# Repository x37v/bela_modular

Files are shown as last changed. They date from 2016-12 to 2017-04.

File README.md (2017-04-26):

# bela_modular

A modular level interface for the bela beagle bone black cape, kicad projects.

[bela](http://bela.io/) is a cape for the beagle bone black

* based off the [audio expansion cape](http://blog.bela.io/analogue-vs-digital/)
* [hardware info](https://github.com/BelaPlatform/Bela/wiki/Hardware-explained)

## Pin mappings

The digital i/o is mapped as such:

|Bela #|	 Board | Note 	 |
|---|--- | ---|
|00 |  in 1 ||
|01 |  in 2 ||
|02 |  in 3 ||
|03 |  in 4 ||
|04 |  digtial in enable | pull low to enable |
|05 |  vfd ctrl enable | pull low to enable |
|06 |  encin2-btn ||
|07 |  encin2-b ||
|08 |  out 1 ||
|09 |  out 2 ||
|10 |  encin2-a ||
|11 |  out 3 ||
|12 |  out 5 ||
|13 |  out 4 ||
|14 |  out 7 ||
|15 |  out 6 ||

### VFD IO

| P8 | | gpio | note |
|:--:|---|---|-- |
| 12 | ctrl enable | 1_12 | mapped in bela software |
| 14 | digital out enable | 0_26 | |
| 31 | P busy in | 0_10 | |
| 34 | vDE | 2_17 | |
| 35 | CS2 | 0_8  | |
| 36 | CS1 | 2_16 | |
| 37 | /RD and RW | 2_14 | |
| 38 | /WR and RS | 2_15 | |
| | | | |
| 39 | D7 | 2_12 | |
| 40 | D6 | 2_13 | |
| 41 | D5 | 2_10 | |
| 42 | D4 | 2_11 | |
| 43 | D3 | 2_8  | |
| 44 | D2 | 2_9  | |
| 45 | D1 | 2_6  | |
| 46 | D0 | 2_7  | |

### Errors/rework

The digital 'extra' board from 3/17 requires a rework for the digital out and
control enable pins [P8 12 and 14]. These should be detached from 5V and
attached to 3.3V.

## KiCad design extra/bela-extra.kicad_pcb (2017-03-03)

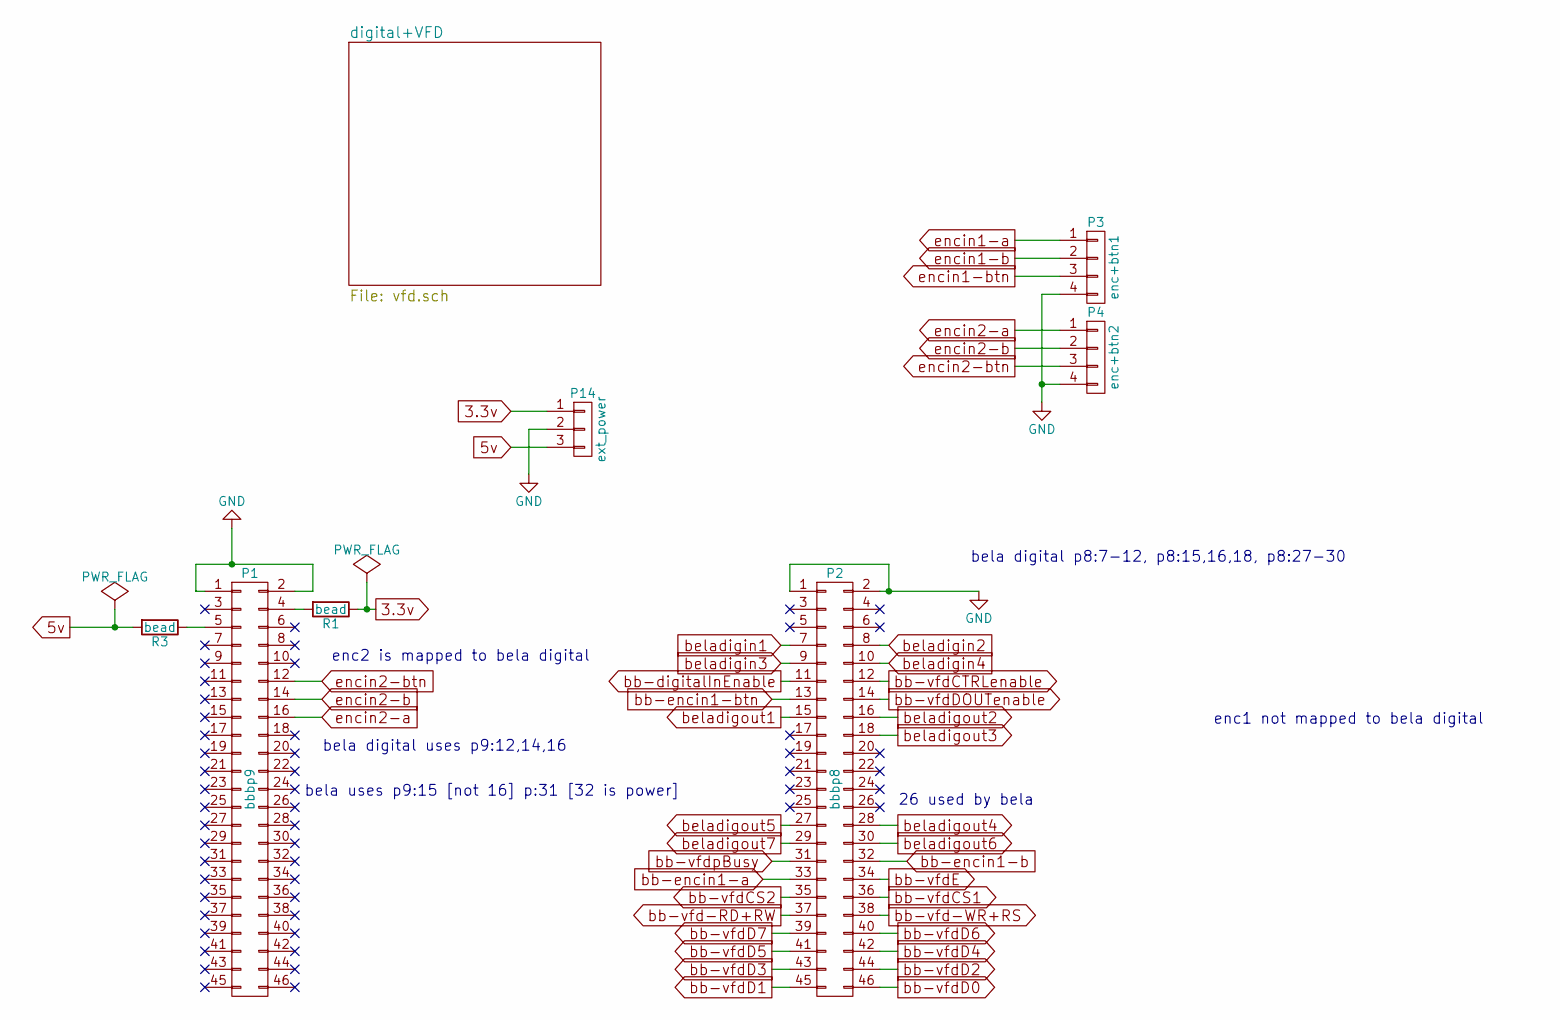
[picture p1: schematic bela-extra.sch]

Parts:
P1: bbbp9; Pin_Header_Straight_2x23_Pitch2.54mm
P2: bbbp8; Pin_Header_Straight_2x23_Pitch2.54mm
P3: enc+btn1; Pin_Header_Straight_1x04_Pitch2.54mm
P4: enc+btn2; Pin_Header_Straight_1x04_Pitch2.54mm
P14: ext_power; Pin_Header_Straight_1x03_Pitch2.54mm
R1, R3: bead; Resistor_Vertical_RM5mm-xnor

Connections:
3.3v: P14.1, R1.1; also elsewhere on the board
5v: P14.3, R3.2; also elsewhere on the board
GND: P1.1, P1.2, P2.1, P2.2, P3.4, P4.4, P14.2; also elsewhere on the board
unnamed: P1.4, R1.2
unnamed: P1.5, R3.1
bb-digitalInEnable: P2.11; also elsewhere on the board
bb-encin1-a: P2.33; also elsewhere on the board
bb-encin1-b: P2.32; also elsewhere on the board
bb-encin1-btn: P2.13; also elsewhere on the board
bb-vfd-RD+RW: P2.37; also elsewhere on the board
bb-vfd-WR+RS: P2.38; also elsewhere on the board
bb-vfdCS1: P2.36; also elsewhere on the board
bb-vfdCS2: P2.35; also elsewhere on the board
bb-vfdCTRLenable: P2.12; also elsewhere on the board
bb-vfdD0: P2.46; also elsewhere on the board
bb-vfdD1: P2.45; also elsewhere on the board
bb-vfdD2: P2.44; also elsewhere on the board
bb-vfdD3: P2.43; also elsewhere on the board
bb-vfdD4: P2.42; also elsewhere on the board
bb-vfdD5: P2.41; also elsewhere on the board
bb-vfdD6: P2.40; also elsewhere on the board
bb-vfdD7: P2.39; also elsewhere on the board
bb-vfdDOUTenable: P2.14; also elsewhere on the board
bb-vfdE: P2.34; also elsewhere on the board
bb-vfdpBusy: P2.31; also elsewhere on the board
beladigin1: P2.7; also elsewhere on the board
beladigin2: P2.8; also elsewhere on the board
beladigin3: P2.9; also elsewhere on the board
beladigin4: P2.10; also elsewhere on the board
beladigout1: P2.15; also elsewhere on the board
beladigout2: P2.16; also elsewhere on the board
beladigout3: P2.18; also elsewhere on the board
beladigout4: P2.28; also elsewhere on the board
beladigout5: P2.27; also elsewhere on the board
beladigout6: P2.30; also elsewhere on the board
beladigout7: P2.29; also elsewhere on the board
encin1-a: P3.1; also elsewhere on the board
encin1-b: P3.2; also elsewhere on the board
encin1-btn: P3.3; also elsewhere on the board
encin2-a: P1.16, P4.1
encin2-b: P1.14, P4.2
encin2-btn: P1.12, P4.3

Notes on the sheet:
enc1 not mapped to bela digital
enc2 is mapped to bela digital
26 used by bela
bela uses p9:15 [not 16] p:31 [32 is power]
bela digital p8:7-12, p8:15,16,18, p8:27-30
bela digital uses p9:12,14,16

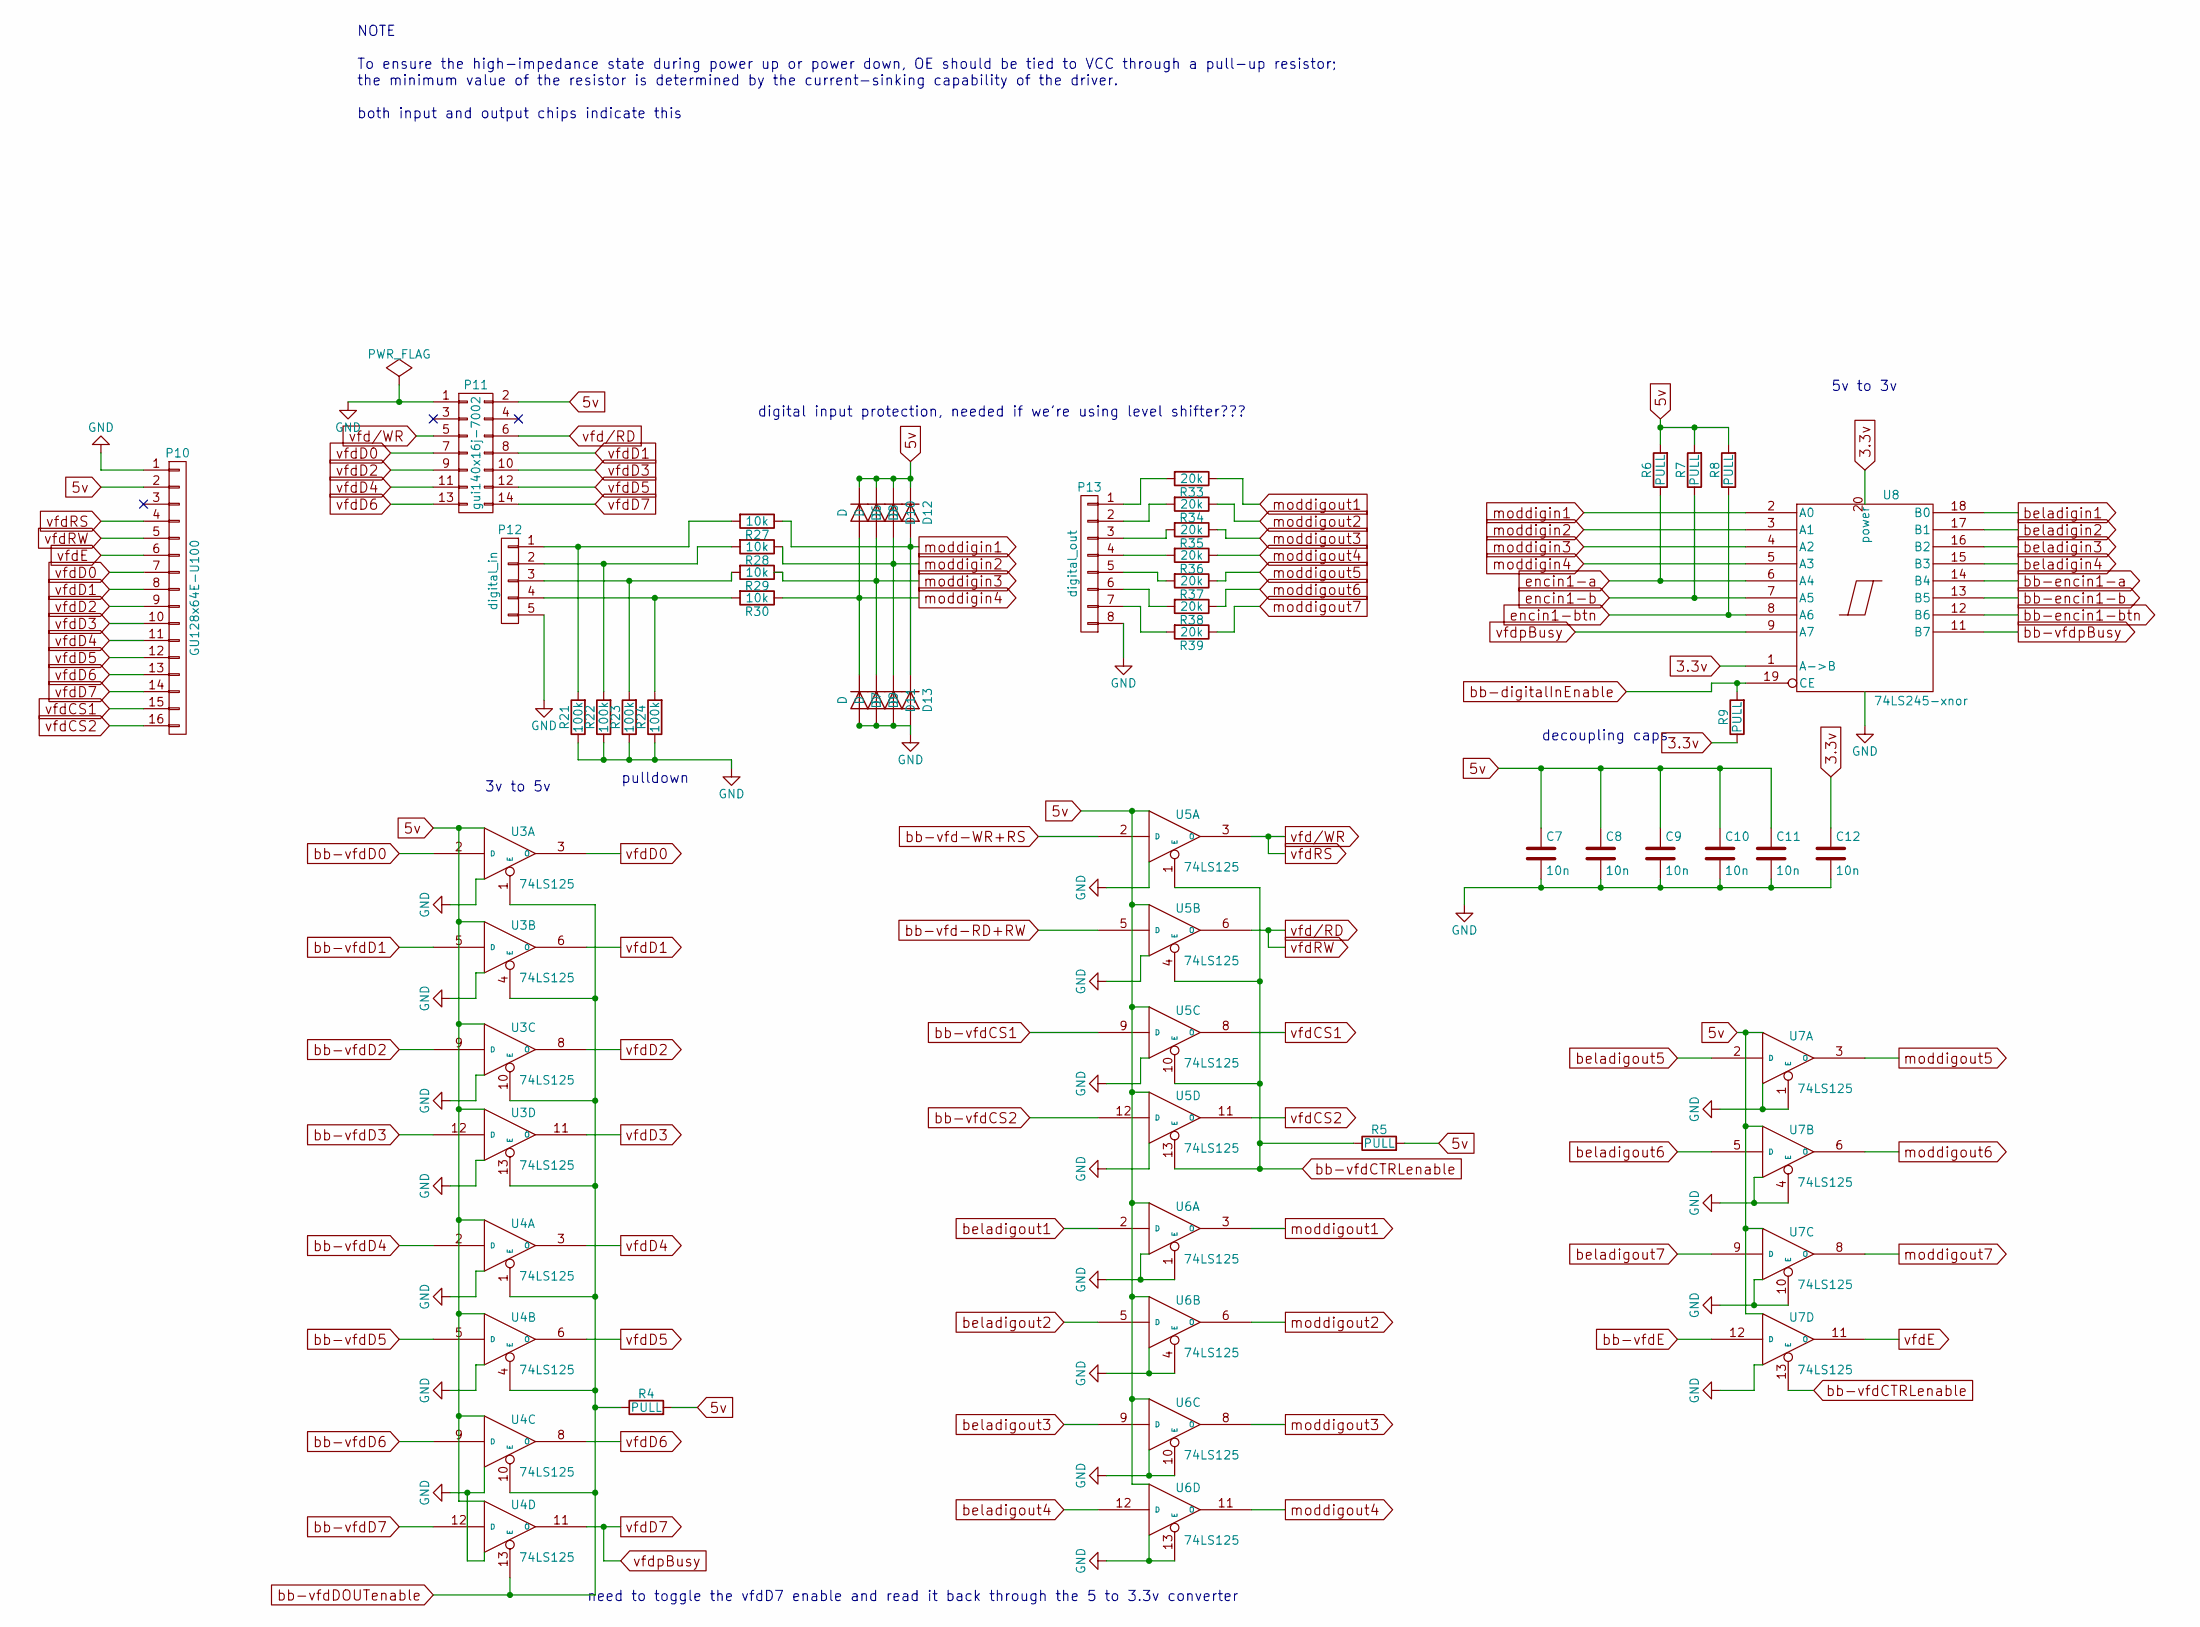
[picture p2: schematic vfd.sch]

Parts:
C7, C8, C9, C10, C11, C12: 10n; C_Rect_L4_W2.5_P2.5
D6, D7, D8, D9, D10, D11, D12, D13: D; D_DO-41_SOD81_P7.62mm_Horizontal
P10: GU128x64E-U100; Pin_Header_Straight_1x16_Pitch2.54mm
P11: gui140x16j-7002; Pin_Header_Straight_2x07_Pitch2.54mm
P12: digital_in; Pin_Header_Straight_1x05_Pitch2.54mm
P13: digital_out; Pin_Header_Straight_1x08_Pitch2.54mm
R4, R5, R6, R7, R8, R9: PULL; Resistor_Horizontal_RM10mm-xnorman
R21, R22, R23, R24: 100k; Resistor_Horizontal_RM10mm-xnorman
R27, R28, R29, R30: 10k; Resistor_Horizontal_RM10mm-xnorman
R33, R34, R35, R36, R37, R38, R39: 20k; Resistor_Horizontal_RM10mm-xnorman
U3, U4, U5, U6, U7: 74LS125; DIP-14_W7.62mm_LongPads
U8: 74LS245-xnor; DIP-20_W7.62mm_LongPads

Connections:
3.3v: C12.1, R9.1, U8.1 (A->B), U8.20 (power); also elsewhere on the board
5v: C7.1, C8.1, C9.1, C10.1, C11.1, D6.1 (K), D8.1 (K), D10.1 (K), D12.1 (K), P10.2, P11.2, R4.2, R5.2, R6.2, R7.2, R8.2, U3.14 (VCC), U4.14 (VCC), U5.14 (VCC), U6.14 (VCC), U7.14 (VCC); also elsewhere on the board
GND: C7.2, C8.2, C9.2, C10.2, C11.2, C12.2, D7.2 (A), D9.2 (A), D11.2 (A), D13.2 (A), P10.1, P11.1, P12.5, P13.8, R21.1, R22.1, R23.1, R24.1, U3.7 (GND), U4.7 (GND), U5.7 (GND), U6.1 (E), U6.4 (E), U6.7 (GND), U6.10 (E), U6.13 (E), U7.1 (E), U7.4 (E), U7.7 (GND), U7.10 (E), U8.10 (GND); also elsewhere on the board
unnamed: P12.1, R21.2, R27.2
unnamed: P12.2, R22.2, R28.2
unnamed: P12.3, R23.2, R29.2
unnamed: P12.4, R24.2, R30.2
unnamed: P13.1, R33.2
unnamed: P13.2, R34.2
unnamed: P13.3, R35.2
unnamed: P13.4, R36.2
unnamed: P13.5, R37.2
unnamed: P13.6, R38.2
unnamed: P13.7, R39.2
bb-digitalInEnable: R9.2, U8.19 (CE); also elsewhere on the board
bb-encin1-a: U8.14 (B4); also elsewhere on the board
bb-encin1-b: U8.13 (B5); also elsewhere on the board
bb-encin1-btn: U8.12 (B6); also elsewhere on the board
bb-vfd-RD+RW: U5.5 (D); also elsewhere on the board
bb-vfd-WR+RS: U5.2 (D); also elsewhere on the board
bb-vfdCS1: U5.9 (D); also elsewhere on the board
bb-vfdCS2: U5.12 (D); also elsewhere on the board
bb-vfdCTRLenable: R5.1, U5.1 (E), U5.4 (E), U5.10 (E), U5.13 (E), U7.13 (E); also elsewhere on the board
bb-vfdD0: U3.2 (D); also elsewhere on the board
bb-vfdD1: U3.5 (D); also elsewhere on the board
bb-vfdD2: U3.9 (D); also elsewhere on the board
bb-vfdD3: U3.12 (D); also elsewhere on the board
bb-vfdD4: U4.2 (D); also elsewhere on the board
bb-vfdD5: U4.5 (D); also elsewhere on the board
bb-vfdD6: U4.9 (D); also elsewhere on the board
bb-vfdD7: U4.12 (D); also elsewhere on the board
bb-vfdDOUTenable: R4.1, U3.1 (E), U3.4 (E), U3.10 (E), U3.13 (E), U4.1 (E), U4.4 (E), U4.10 (E), U4.13 (E); also elsewhere on the board
bb-vfdE: U7.12 (D); also elsewhere on the board
bb-vfdpBusy: U8.11 (B7); also elsewhere on the board
beladigin1: U8.18 (B0); also elsewhere on the board
beladigin2: U8.17 (B1); also elsewhere on the board
beladigin3: U8.16 (B2); also elsewhere on the board
beladigin4: U8.15 (B3); also elsewhere on the board
beladigout1: U6.2 (D); also elsewhere on the board
beladigout2: U6.5 (D); also elsewhere on the board
beladigout3: U6.9 (D); also elsewhere on the board
beladigout4: U6.12 (D); also elsewhere on the board
beladigout5: U7.2 (D); also elsewhere on the board
beladigout6: U7.5 (D); also elsewhere on the board
beladigout7: U7.9 (D); also elsewhere on the board
encin1-a: R6.1, U8.6 (A4); also elsewhere on the board
encin1-b: R7.1, U8.7 (A5); also elsewhere on the board
encin1-btn: R8.1, U8.8 (A6); also elsewhere on the board
moddigin1: D12.2 (A), D13.1 (K), R27.1, U8.2 (A0)
moddigin2: D10.2 (A), D11.1 (K), R28.1, U8.3 (A1)
moddigin3: D8.2 (A), D9.1 (K), R29.1, U8.4 (A2)
moddigin4: D6.2 (A), D7.1 (K), R30.1, U8.5 (A3)
moddigout1: R33.1, U6.3 (O)
moddigout2: R34.1, U6.6 (O)
moddigout3: R35.1, U6.8 (O)
moddigout4: R36.1, U6.11 (O)
moddigout5: R37.1, U7.3 (O)
moddigout6: R38.1, U7.6 (O)
moddigout7: R39.1, U7.8 (O)
vfd/RD: P10.5, P11.6, U5.6 (O)
vfd/WR: P10.4, P11.5, U5.3 (O)
vfdCS1: P10.15, U5.8 (O)
vfdCS2: P10.16, U5.11 (O)
vfdD0: P10.7, P11.7, U3.3 (O)
vfdD1: P10.8, P11.8, U3.6 (O)
vfdD2: P10.9, P11.9, U3.8 (O)
vfdD3: P10.10, P11.10, U3.11 (O)
vfdD4: P10.11, P11.11, U4.3 (O)
vfdD5: P10.12, P11.12, U4.6 (O)
vfdD6: P10.13, P11.13, U4.8 (O)
vfdD7: P10.14, P11.14, U4.11 (O), U8.9 (A7)
vfdE: P10.6, U7.11 (O)

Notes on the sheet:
3v to 5v
5v to 3v
need to toggle the vfdD7 enable and read it back through the 5 to 3.3v converter
NOTE To ensure the high-impedance state during power up or power down, OE should be tied to VCC through a pull-up resistor; the minimum value of the resistor is determined by the current-sinking capability of the driver. both input and output chips indicate this
digital input protection, needed if we're using level shifter???
pulldown
decoupling caps

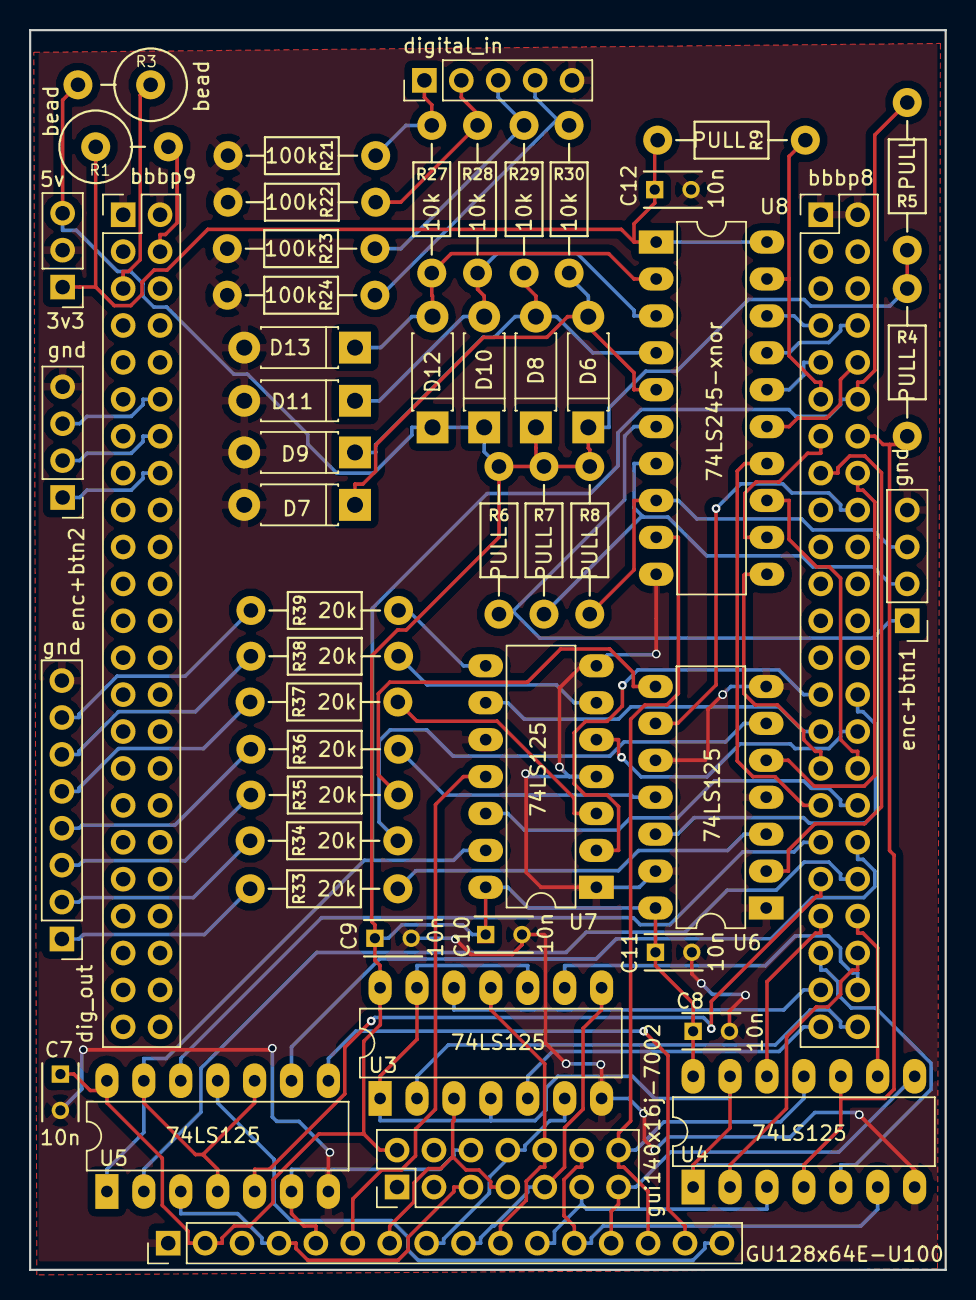
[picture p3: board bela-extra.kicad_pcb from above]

Board: 2 copper layers, 63.0 x 85.3 mm, 52 parts (0 on the bottom side), 77 nets.

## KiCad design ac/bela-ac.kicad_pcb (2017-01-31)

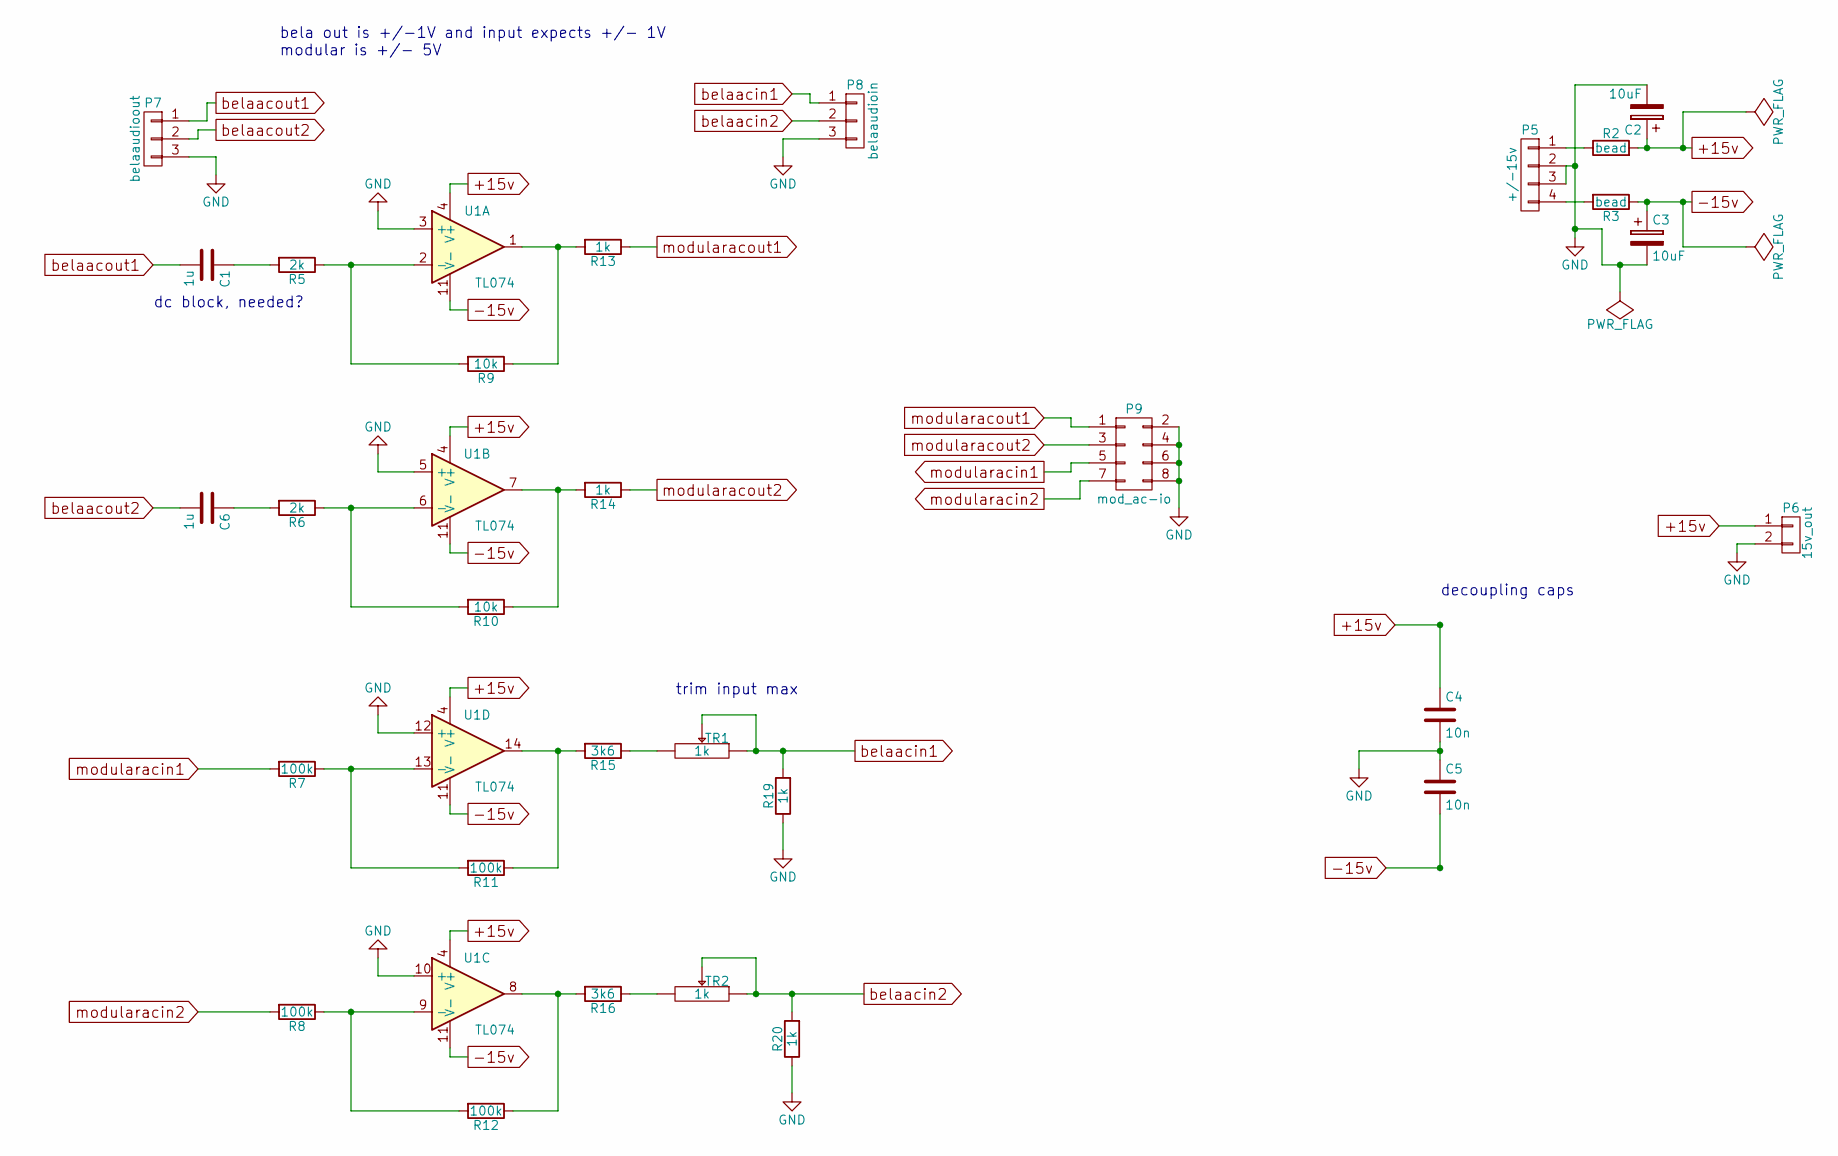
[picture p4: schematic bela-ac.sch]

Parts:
C1, C6: 1u; C_Rect_L4_W2.5_P2.5
C2, C3: 10uF; C_Radial_D5_L11_P2
C4, C5: 10n; C_Rect_L4_W2.5_P2.5
P5: +/-15v; MTA-156-4
P6: 15v_out; MTA-156-2
P7: belaaudioout; Pin_Header_Straight_1x03_Pitch2.54mm
P8: belaaudioin; Pin_Header_Straight_1x03_Pitch2.54mm
P9: mod_ac-io; Pin_Header_Straight_2x04_Pitch2.54mm
R2, R3: bead; Resistor_Vertical_RM5mm-xnor
R5, R6: 2k; Resistor_Horizontal_RM10mm-xnorman
R7, R8, R11, R12: 100k; Resistor_Horizontal_RM10mm-xnorman
R9, R10: 10k; Resistor_Horizontal_RM10mm-xnorman
R13, R14, R19, R20: 1k; Resistor_Horizontal_RM10mm-xnorman
R15, R16: 3k6; Resistor_Horizontal_RM10mm-xnorman
TR1, TR2: 1k; trimmer
U1: TL074; DIP-14_W7.62mm_LongPads

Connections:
+15v: C2.1, C4.1, P6.1, R2.2, U1.4 (V+)
-15v: C3.1, C5.2, R3.1, U1.11 (V-)
GND: C2.2, C3.2, C4.2, C5.1, P5.2, P5.3, P6.2, P7.3, P8.3, P9.2, P9.4, P9.6, P9.8, R19.1, R20.1, U1.3 (+), U1.5 (+), U1.10 (+), U1.12 (+)
unnamed: C1.1, R5.2
unnamed: C6.1, R6.2
unnamed: P5.1, R2.1
unnamed: P5.4, R3.2
unnamed: R5.1, R9.2, U1.2 (-)
unnamed: R10.1, R14.2, U1.7
unnamed: R6.1, R10.2, U1.6 (-)
unnamed: R11.1, R15.2, U1.14
unnamed: R7.1, R11.2, U1.13 (-)
unnamed: R12.1, R16.2, U1.8
unnamed: R8.1, R12.2, U1.9 (-)
unnamed: R9.1, R13.2, U1.1
unnamed: R15.1, TR1.3
unnamed: R16.1, TR2.3
belaacin1: P8.1, R19.2, TR1.1, TR1.2
belaacin2: P8.2, R20.2, TR2.1, TR2.2
belaacout1: C1.2, P7.1
belaacout2: C6.2, P7.2
modularacin1: P9.5, R7.2
modularacin2: P9.7, R8.2
modularacout1: P9.1, R13.1
modularacout2: P9.3, R14.1

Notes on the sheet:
bela out is +/-1V and input expects +/- 1V modular is +/- 5V
decoupling caps
trim input max
dc block, needed?

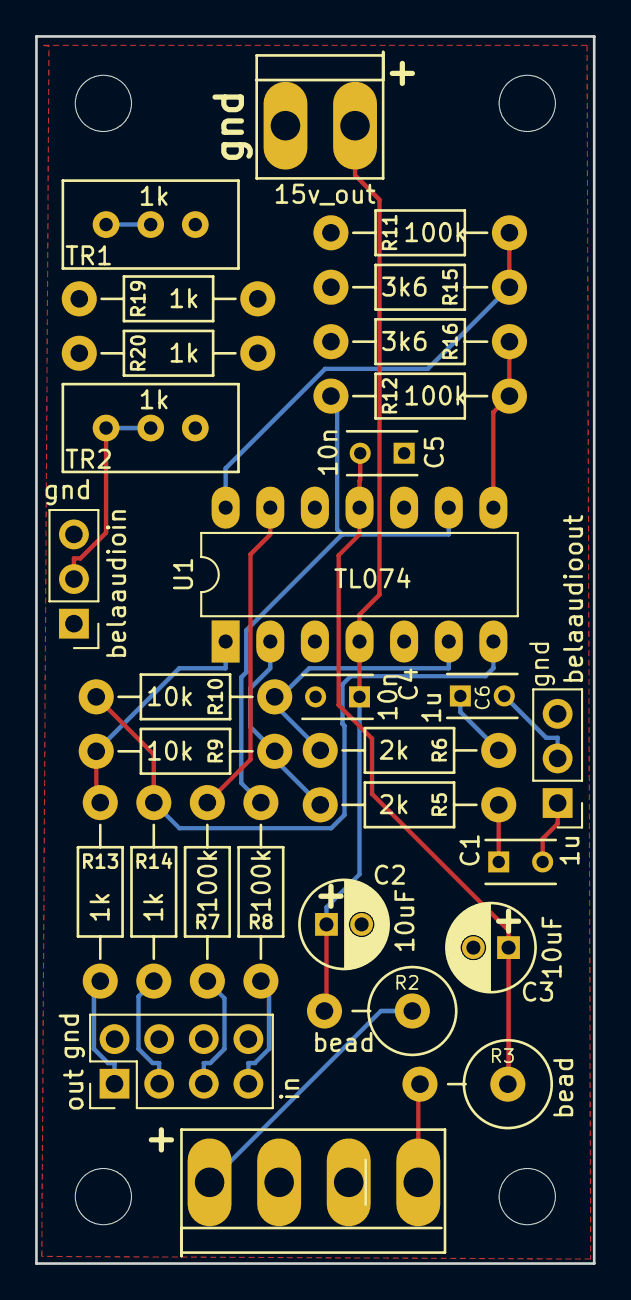
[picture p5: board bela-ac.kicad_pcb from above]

Board: 2 copper layers, 31.8 x 69.9 mm, 34 parts (0 on the bottom side), 25 nets.

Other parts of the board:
REF1, REF2, REF3, REF4: MountingHole_3.2mm_M3

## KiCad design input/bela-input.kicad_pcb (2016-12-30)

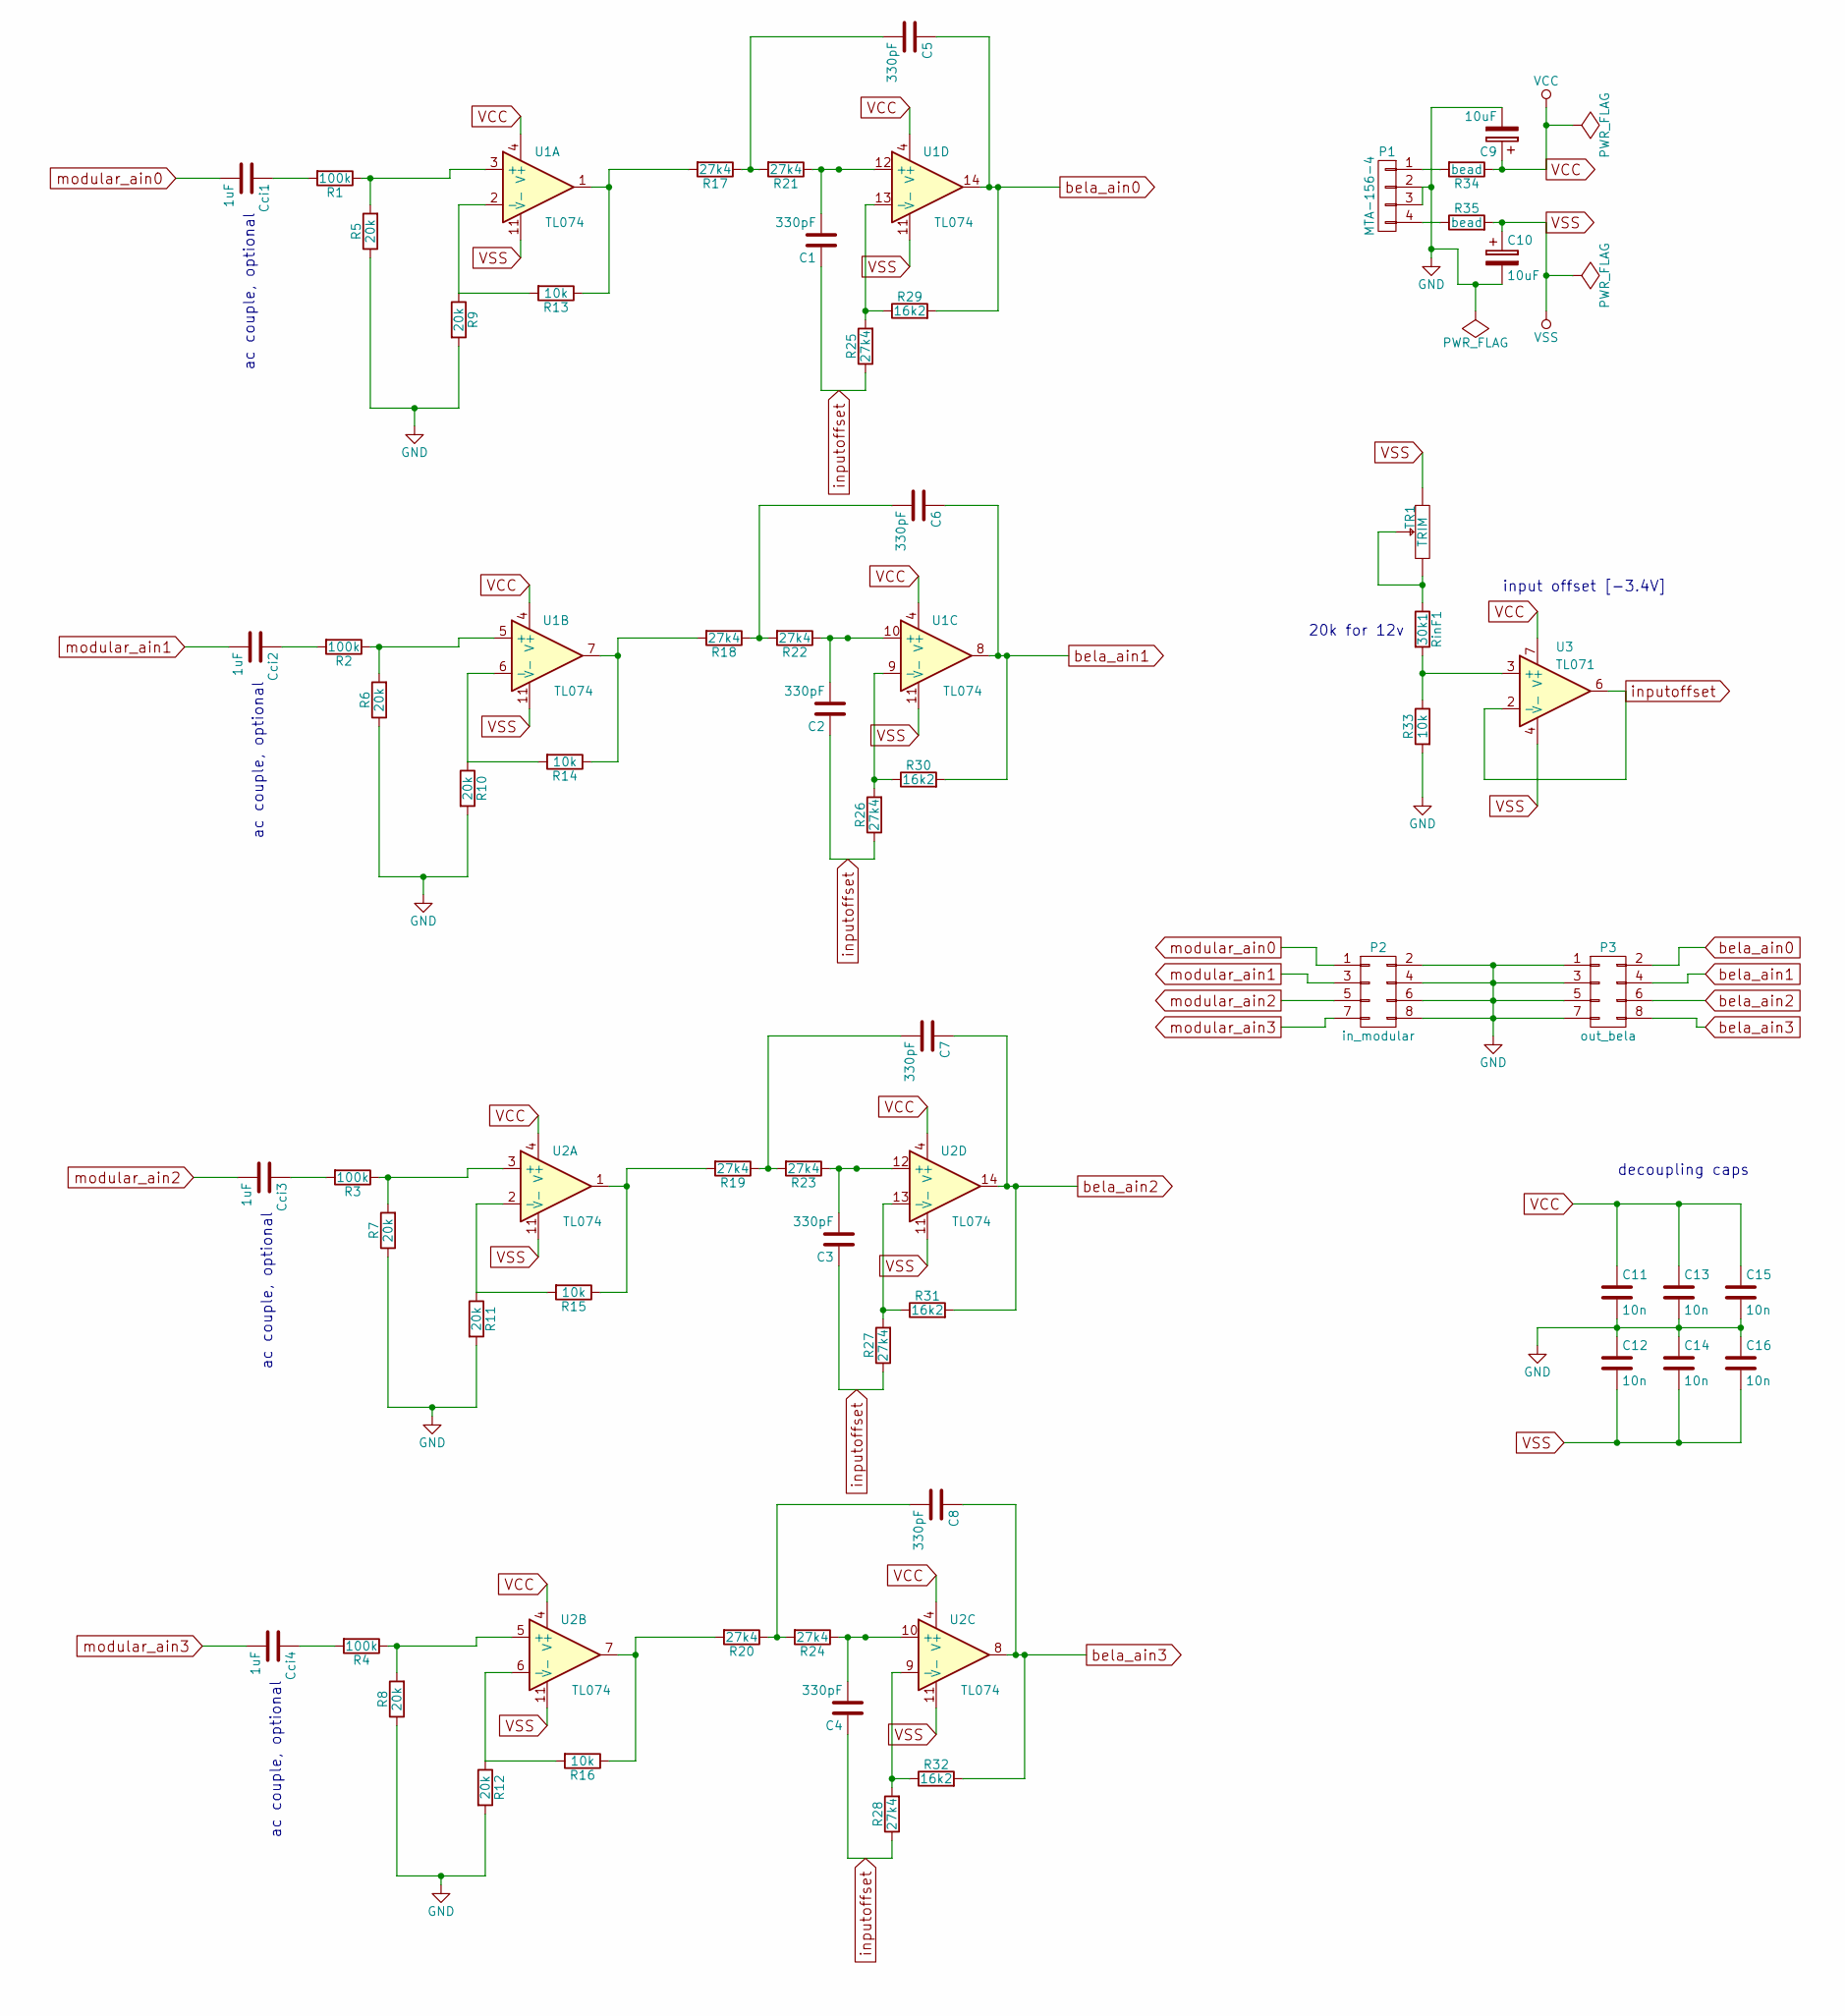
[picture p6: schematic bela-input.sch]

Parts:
C1, C2, C3, C4, C5, C6, C7, C8: 330pF; C_Rect_L4_W2.5_P2.5
C9, C10: 10uF; C_Radial_D5_L11_P2
C11, C12, C13, C14, C15, C16: 10n; C_Rect_L4_W2.5_P2.5
Cci1, Cci2, Cci3, Cci4: 1uF; C_Rect_L4_W2.5_P2.5
P1: MTA-156-4
P2: in_modular; Pin_Header_Straight_2x04
P3: out_bela; Pin_Header_Straight_2x04
R1, R2, R3, R4: 100k; Resistor_Horizontal_RM10mm-xnorman
R5, R6, R7, R8, R9, R10, R11, R12: 20k; Resistor_Horizontal_RM10mm-xnorman
R13, R14, R15, R16, R33: 10k; Resistor_Horizontal_RM10mm-xnorman
R17, R18, R19, R20, R21, R22, R23, R24, R25, R26, R27, R28: 27k4; Resistor_Horizontal_RM10mm-xnorman
R29, R30, R31, R32: 16k2; Resistor_Horizontal_RM10mm-xnorman
R34, R35: bead; Resistor_Vertical_RM5mm-xnor
RinF1: 30k1; Resistor_Horizontal_RM10mm-xnorman
TR1: TRIM; trimmer
U1, U2: TL074; DIP-14_W7.62mm_LongPads
U3: TL071; DIP-8_W7.62mm_LongPads

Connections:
GND: C9.2, C10.2, C11.2, C12.1, C13.2, C14.1, C15.2, C16.1, P1.2, P1.3, P2.2, P2.4, P2.6, P2.8, P3.1, P3.3, P3.5, P3.7, R5.1, R6.1, R7.1, R8.1, R9.2, R10.2, R11.2, R12.2, R33.2
unnamed: C1.2, R21.1, U1.12 (+)
unnamed: C2.2, R22.1, U1.10 (+)
unnamed: C3.2, R23.1, U2.12 (+)
unnamed: C4.2, R24.1, U2.10 (+)
unnamed: C5.2, R17.1, R21.2
unnamed: C6.2, R18.1, R22.2
unnamed: C7.2, R19.1, R23.2
unnamed: C8.2, R20.1, R24.2
unnamed: Cci1.1, R1.2
unnamed: Cci2.1, R2.2
unnamed: Cci3.1, R3.2
unnamed: Cci4.1, R4.2
unnamed: P1.1, R34.2
unnamed: P1.4, R35.1
unnamed: R1.1, R5.2, U1.3 (+)
unnamed: R2.1, R6.2, U1.5 (+)
unnamed: R3.1, R7.2, U2.3 (+)
unnamed: R4.1, R8.2, U2.5 (+)
unnamed: R10.1, R14.2, U1.6 (-)
unnamed: R11.1, R15.2, U2.2 (-)
unnamed: R12.1, R16.2, U2.6 (-)
unnamed: R13.1, R17.2, U1.1
unnamed: R9.1, R13.2, U1.2 (-)
unnamed: R14.1, R18.2, U1.7
unnamed: R15.1, R19.2, U2.1
unnamed: R16.1, R20.2, U2.7
unnamed: R25.2, R29.1, U1.13 (-)
unnamed: R26.2, R30.1, U1.9 (-)
unnamed: R27.2, R31.1, U2.13 (-)
unnamed: R28.2, R32.1, U2.9 (-)
unnamed: R33.1, RinF1.2, U3.3 (+)
unnamed: RinF1.1, TR1.2, TR1.3
VCC: C9.1, C11.1, C13.1, C15.1, R34.1, U1.4 (V+), U2.4 (V+), U3.7 (V+)
VSS: C10.1, C12.2, C14.2, C16.2, R35.2, TR1.1, U1.11 (V-), U2.11 (V-), U3.4 (V-)
bela_ain0: C5.1, P3.2, R29.2, U1.14
bela_ain1: C6.1, P3.4, R30.2, U1.8
bela_ain2: C7.1, P3.6, R31.2, U2.14
bela_ain3: C8.1, P3.8, R32.2, U2.8
inputoffset: C1.1, C2.1, C3.1, C4.1, R25.1, R26.1, R27.1, R28.1, U3.2 (-), U3.6
modular_ain0: Cci1.2, P2.1
modular_ain1: Cci2.2, P2.3
modular_ain2: Cci3.2, P2.5
modular_ain3: Cci4.2, P2.7

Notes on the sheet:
ac couple, optional
20k for 12v
input offset [-3.4V]
decoupling caps

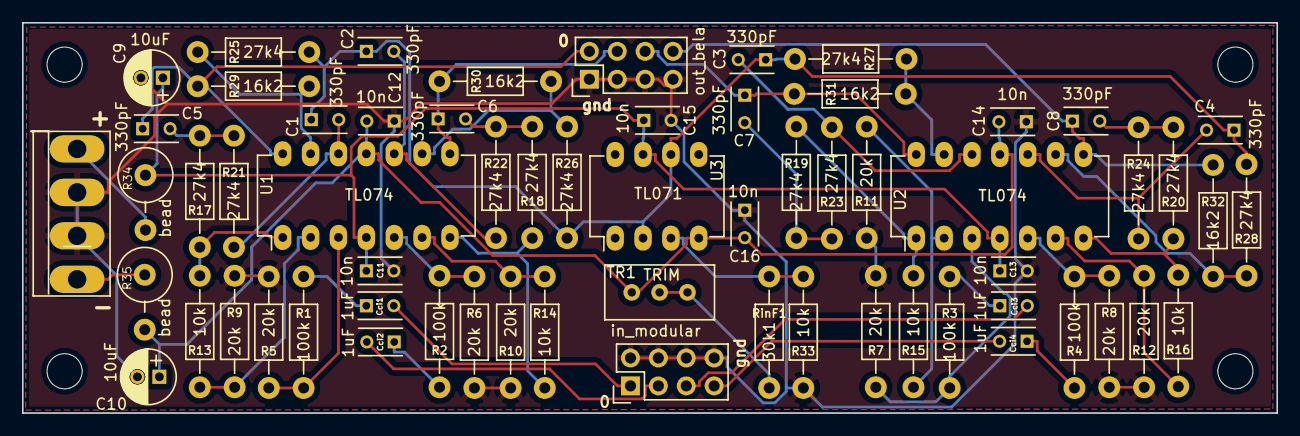
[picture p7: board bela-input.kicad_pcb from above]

Board: 2 copper layers, 114.3 x 35.6 mm, 67 parts (0 on the bottom side), 44 nets.

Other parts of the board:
REF1, REF2, REF3, REF4: MountingHole_3.2mm_M3

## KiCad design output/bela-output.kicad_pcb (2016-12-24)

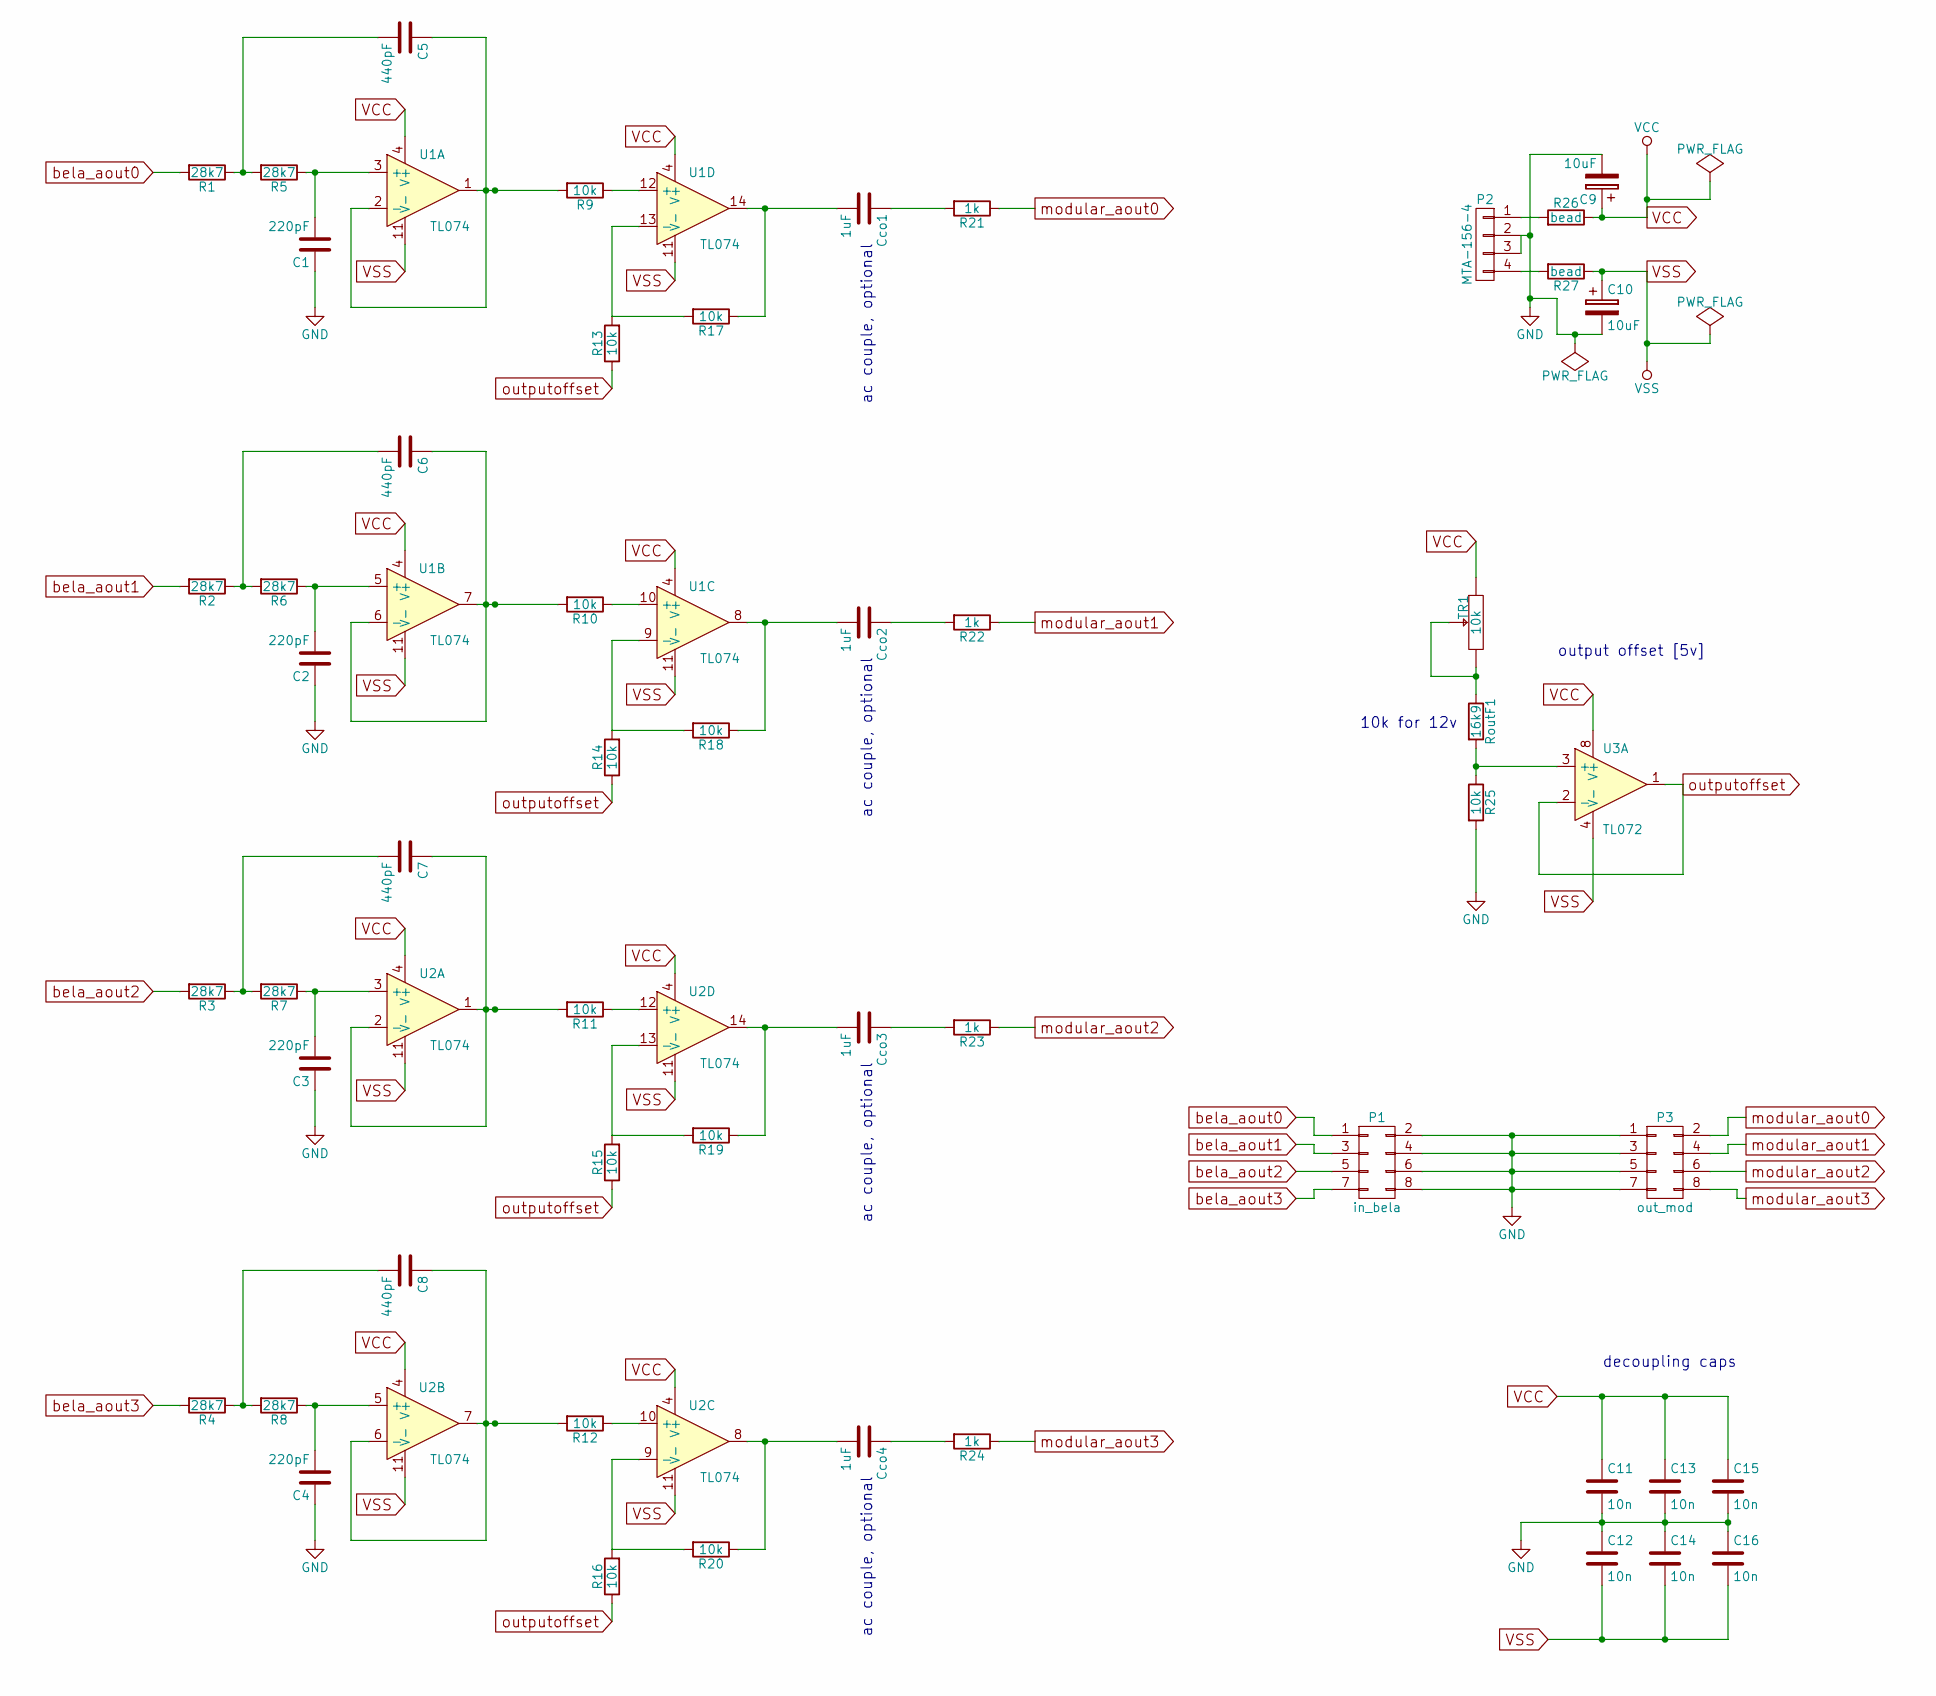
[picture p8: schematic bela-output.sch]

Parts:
C1, C2, C3, C4: 220pF; C_Rect_L4_W2.5_P2.5
C5, C6, C7, C8: 440pF; C_Rect_L4_W2.5_P2.5
C9, C10: 10uF; C_Radial_D5_L11_P2
C11, C12, C13, C14, C15, C16: 10n; C_Rect_L4_W2.5_P2.5
Cco1, Cco2, Cco3, Cco4: 1uF; C_Rect_L4_W2.5_P2.5
P1: in_bela; Pin_Header_Straight_2x04
P2: MTA-156-4
P3: out_mod; Pin_Header_Straight_2x04
R1, R2, R3, R4, R5, R6, R7, R8: 28k7; Resistor_Horizontal_RM10mm
R9, R10, R11, R12, R13, R14, R15, R16, R17, R18, R19, R20, R25: 10k; Resistor_Horizontal_RM10mm
R21, R22, R23, R24: 1k; Resistor_Horizontal_RM10mm
R26, R27: bead; Resistor_Vertical_RM5mm
RoutF1: 16k9; Resistor_Horizontal_RM10mm
TR1: 10k; trimmer
U1, U2: TL074; DIP-14_W7.62mm_LongPads
U3: TL072; DIP-8_W7.62mm_LongPads

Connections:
GND: C1.1, C2.1, C3.1, C4.1, C9.2, C10.2, C11.2, C12.1, C13.2, C14.1, C15.2, C16.1, P1.2, P1.4, P1.6, P1.8, P2.2, P2.3, P3.1, P3.3, P3.5, P3.7, R25.2
unnamed: C1.2, R5.1, U1.3 (+)
unnamed: C2.2, R6.1, U1.5 (+)
unnamed: C3.2, R7.1, U2.3 (+)
unnamed: C4.2, R8.1, U2.5 (+)
unnamed: C5.1, R9.2, U1.1, U1.2 (-)
unnamed: C5.2, R1.1, R5.2
unnamed: C6.1, R10.2, U1.6 (-), U1.7
unnamed: C6.2, R2.1, R6.2
unnamed: C7.1, R11.2, U2.1, U2.2 (-)
unnamed: C7.2, R3.1, R7.2
unnamed: C8.1, R12.2, U2.6 (-), U2.7
unnamed: C8.2, R4.1, R8.2
unnamed: Cco1.1, R21.2
unnamed: Cco1.2, R17.1, U1.14
unnamed: Cco2.1, R22.2
unnamed: Cco2.2, R18.1, U1.8
unnamed: Cco3.1, R23.2
unnamed: Cco3.2, R19.1, U2.14
unnamed: Cco4.1, R24.2
unnamed: Cco4.2, R20.1, U2.8
unnamed: P2.1, R26.2
unnamed: P2.4, R27.2
unnamed: R9.1, U1.12 (+)
unnamed: R10.1, U1.10 (+)
unnamed: R11.1, U2.12 (+)
unnamed: R12.1, U2.10 (+)
unnamed: R13.2, R17.2, U1.13 (-)
unnamed: R14.2, R18.2, U1.9 (-)
unnamed: R15.2, R19.2, U2.13 (-)
unnamed: R16.2, R20.2, U2.9 (-)
unnamed: R25.1, RoutF1.2, U3.3 (+)
unnamed: RoutF1.1, TR1.2, TR1.3
VCC: C9.1, C11.1, C13.1, C15.1, R26.1, TR1.1, U1.4 (V+), U2.4 (V+), U3.8 (V+)
VSS: C10.1, C12.2, C14.2, C16.2, R27.1, U1.11 (V-), U2.11 (V-), U3.4 (V-)
bela_aout0: P1.1, R1.2
bela_aout1: P1.3, R2.2
bela_aout2: P1.5, R3.2
bela_aout3: P1.7, R4.2
modular_aout0: P3.2, R21.1
modular_aout1: P3.4, R22.1
modular_aout2: P3.6, R23.1
modular_aout3: P3.8, R24.1
outputoffset: R13.1, R14.1, R15.1, R16.1, U3.1, U3.2 (-)

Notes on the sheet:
ac couple, optional
10k for 12v
output offset [5v]
decoupling caps

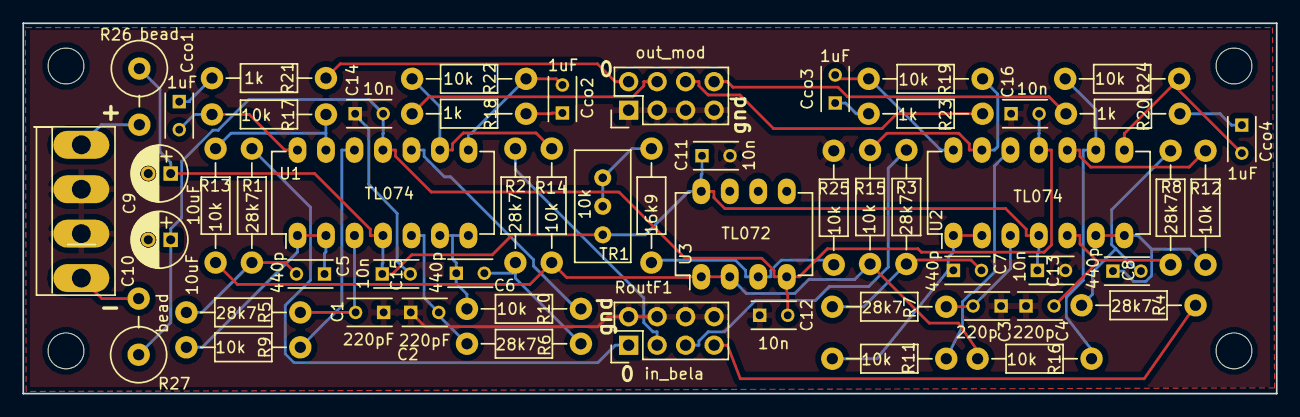
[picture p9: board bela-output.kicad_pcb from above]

Board: 2 copper layers, 111.8 x 33.0 mm, 59 parts (0 on the bottom side), 44 nets.

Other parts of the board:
REF1, REF2, REF3, REF4: MountingHole_3.2mm_M3

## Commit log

2016-12-03 initial schematic
    [bela-modular.kicad_pcb, bela-modular.sch, inputprocess.sch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]
2016-12-04 created an input only project, moved other to all
    [bela-input.kicad_pcb, bela-input.sch, bela-modular.kicad_pcb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]
2016-12-05 major updates! nearly done with input
    [bela-input.kicad_pcb, bela-input.sch]
2016-12-06 moved things around, moved more to F.SilkS
    [bela-input.kicad_pcb]
2016-12-06 added more PCB documentation and moved some stuff
    [bela-input.kicad_pcb]
2016-12-06 working on analog output pcb
    [bela-output.kicad_pcb, bela-output.sch]
2016-12-11 mostly layed out, veridical resistors
    [bela-output.kicad_pcb]
2016-12-11 flush resistor layout
    [bela-output.kicad_pcb, bela-output.sch]
2016-12-11 added top filled gnd zone
    [bela-output.kicad_pcb]
2016-12-11 moved text for output
    [bela-output.kicad_pcb]
2016-12-11 relayout of input
    [bela-input.kicad_pcb, bela-input.sch]
2016-12-11 added gnd and 0 and 10k on trim
    [bela-output.kicad_pcb]
2016-12-19 last part for the digital + ac coupled
    [acanalog.sch, bela-extra.kicad_pcb, bela-extra.sch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]
2016-12-19 more updates, mostly notes and input/output direction changes
    [acanalog.sch, bela-extra.sch, vfd.sch]
2016-12-24 added + for polar caps
    [bela-input.kicad_pcb, bela-output.kicad_pcb]
2016-12-30 oops, forgot to connect the grounds
    [bela-input.kicad_pcb, bela-input.sch]
2016-12-30 connected up grounds on input board
    [bela-input.kicad_pcb]
2017-01-03 much more work on vfd [2 parallel interfaces]
    [bela-extra.sch, vfd.sch]
2017-01-03 a bunch more hooking up
    [bela-extra.sch, vfd.sch]
2017-01-03 added pulldowns for digital inputs
    [vfd.sch]
2017-01-04 a lot more layout work
    [acanalog.sch, bela-extra.sch, vfd.sch]
2017-01-04 starting pcb layout a little
    [acanalog.sch, bela-extra.kicad_pcb, bela-extra.sch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]
2017-01-05 moving along, still no idea why 5v is hooked to 3.3v
    [acanalog.sch, bela-extra.kicad_pcb, bela-extra.sch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]
2017-01-06 fixed up some footprint issues
    [bela-extra.kicad_pcb, bela-extra.sch, vfd.sch]
2017-01-06 3.3v is no longer connected to 5v!
    [acanalog.sch, bela-extra.kicad_pcb, bela-extra.sch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]
2017-01-08 added decoupling caps, power expand, more layout
    [acanalog.sch, bela-extra.kicad_pcb, bela-extra.sch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]
2017-01-08 more layout, gonna split into 2 boards
    [bela-extra.kicad_pcb]
2017-01-08 moved ac over to its own board
    [acanalog.sch, bela-ac.kicad_pcb, bela-ac.sch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]
2017-01-08 consolidated schematics etc
    [acanalog.sch, bela-ac.kicad_pcb, bela-ac.sch]
2017-01-08 removed ac from extra, added power connection for 15
    [bela-ac.kicad_pcb, bela-ac.sch, bela-extra.kicad_pcb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]
2017-01-08 added trimmer, removed b.s., almost ready to route
    [bela-ac.kicad_pcb, bela-ac.sch, vfd.sch]
2017-01-08 totally routed, added labels
    [bela-ac.kicad_pcb]
2017-01-08 moved some labels to make things more clear
    [bela-ac.kicad_pcb]
2017-01-08 changed visibility
    [bela-ac.kicad_pcb]
2017-01-08 fixed up labeling
    [bela-extra.kicad_pcb, bela-extra.sch]
2017-01-08 all layed out
    [bela-extra.kicad_pcb]
2017-01-30 exchanged bad parts on ac board, though haven't placed yet
    [bela-ac.kicad_pcb]
2017-01-31 Revert "exchanged bad parts on ac board, though haven't placed yet"
    This reverts commit 3185bdf4a96cd7a989377c24179a0fe5be16ab20.
    [bela-ac.kicad_pcb]
2017-01-31 got the correct part in, AND the mounting holes
    [bela-ac.kicad_pcb]
2017-02-08 working with enables on extra board
    [bela-extra.sch, vfd.sch]
2017-02-10 ditched power, remapped a bunch of io
    should have all the emmc and lcd lines disabled at boot
    [bela-extra.kicad_pcb, bela-extra.sch, vfd.sch]
2017-03-03 connected up the rest of the extra board
    [bela-extra.kicad_pcb]
2017-03-03 fixed up some labels
    [bela-extra.kicad_pcb]
2017-04-23 updated pin mapping
